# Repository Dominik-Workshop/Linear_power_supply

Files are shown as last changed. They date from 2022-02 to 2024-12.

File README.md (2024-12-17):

# Linear power supply

> [!CAUTION]
> This project was initiated in 2021 when my skills were more limited. As a result, there might be areas for improvement. I occasionally enhance both the performance and readability of project files for better understanding.

### More info about this project can be found on my channel: 
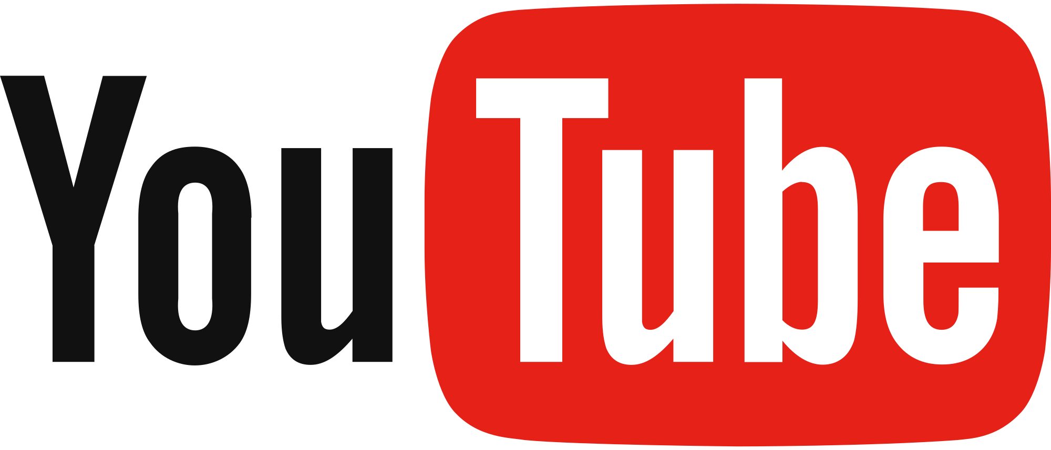
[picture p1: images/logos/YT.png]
 https://youtu.be/JCxF-o6tLgA

## Used tools:
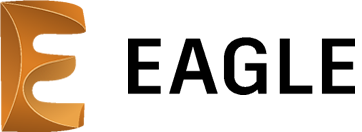
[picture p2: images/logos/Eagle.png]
 &nbsp;&nbsp;&nbsp;&nbsp; &nbsp;&nbsp;&nbsp;&nbsp; 
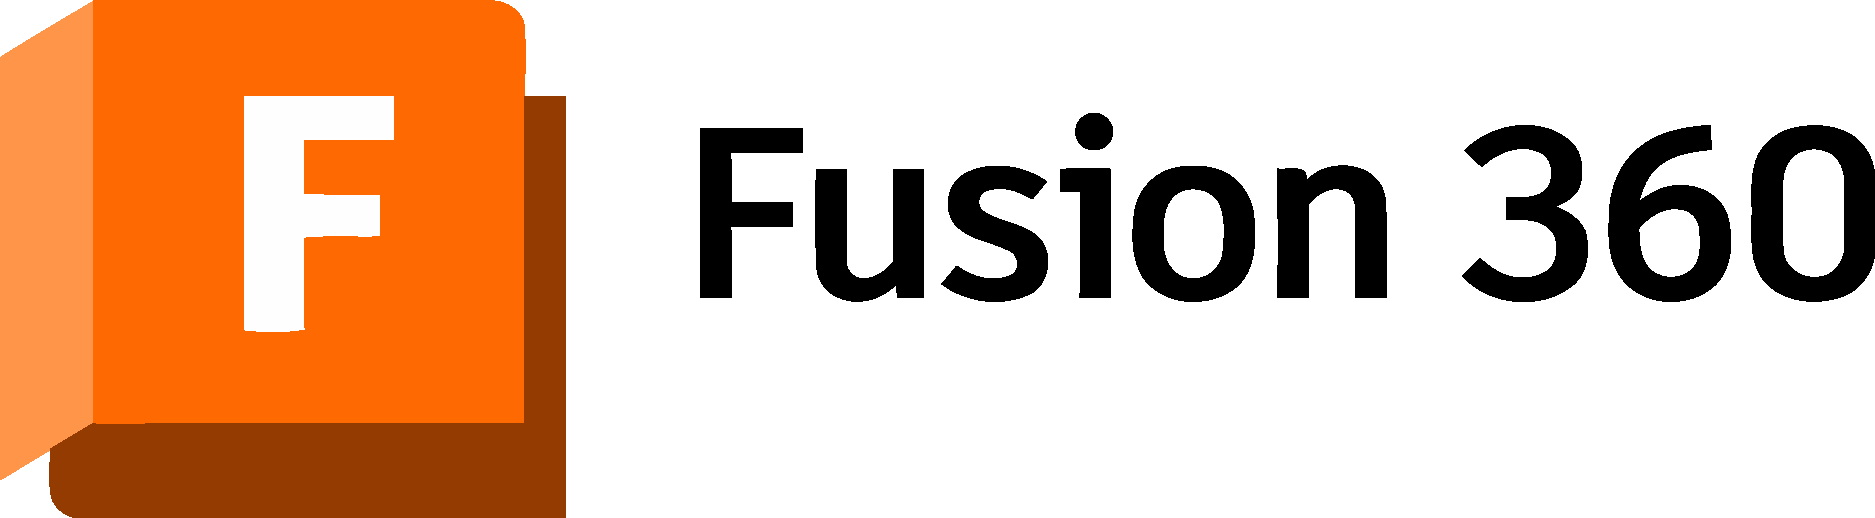
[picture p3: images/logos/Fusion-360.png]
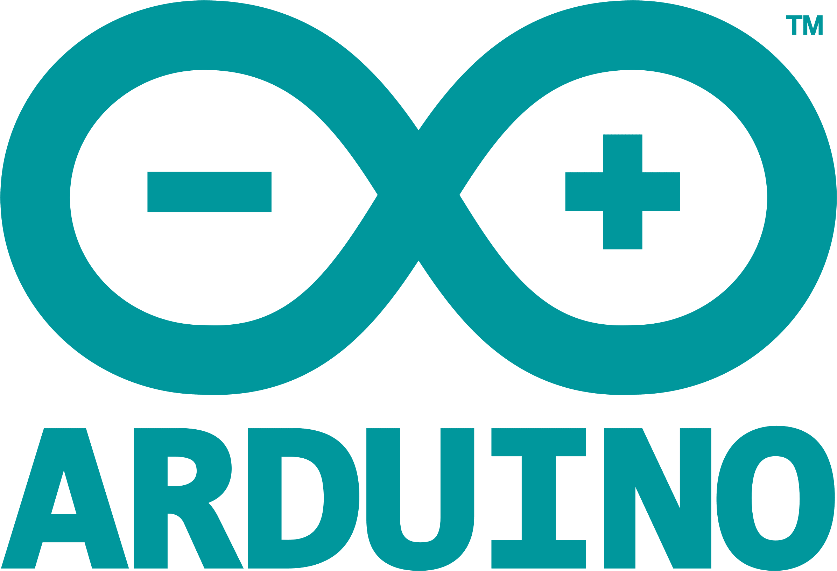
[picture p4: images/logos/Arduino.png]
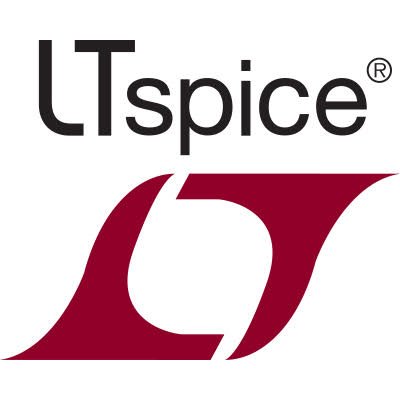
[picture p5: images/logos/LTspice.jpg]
&nbsp;&nbsp;&nbsp;&nbsp; &nbsp;&nbsp;&nbsp;&nbsp; &nbsp;&nbsp;&nbsp;&nbsp; &nbsp;&nbsp;&nbsp;&nbsp; 
#

## Project Overview
- Homemade linear power supply capable of delivering up to 250W (0-28V, 0.01-10A)
- Features adjustable voltage and current limit, controlled by 10-turn potentiometers.
- Incorporates an on/off switch for convenient power control.
- Utilizes a relay transformer-tab switching circuit to minimize power losses by reducing the voltage differential across the linear regulator.
- Enhanced heat dissipation through a temperature-controlled fan cooling the heatsink.

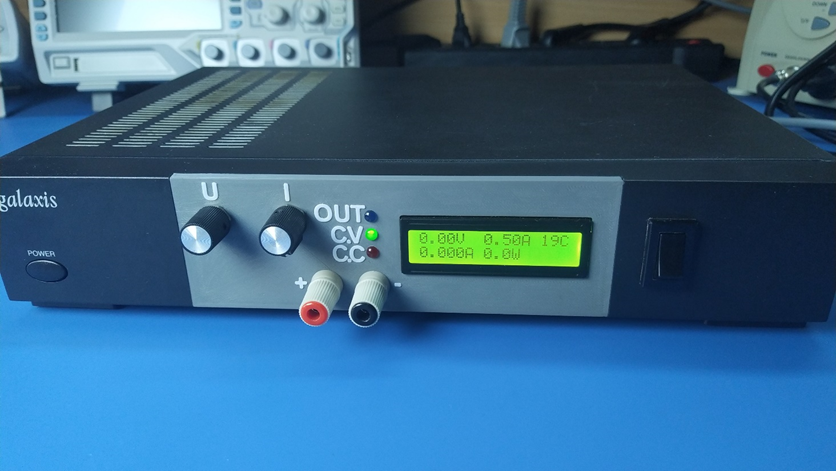
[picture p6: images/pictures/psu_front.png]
 

> [!IMPORTANT]
> I changed the Q1 transistor from IRF9530 (P-MOSFET) to BD912 (PNP-BJT) to greatly improve the stability of this power supply and completely eliminate oscillations in the constant current mode. (Their pinouts match, so it is a drop-in replacement)
> <details>
> <summary>Click to learn more</summary>
> After performing some simulations in LTspice, I figured out that simply changing the Q1 MOSFET to a BJT greatly improved the output response to input step:
>
> Before (with MOSFET):
> <image src="images/screenshots/old_step.png">
> After (with BJT):
> <image src="images/screenshots/new_step.png">
> (The bode plot also looks better)
> </details>

## Output Measurements
Output voltage waveforms before changing Q1 to a BJT can be found in measurements.pdf

## Project details
I used this 12 300VA transformer, which I slightly modified. The secondary winding consisted of 4 wires connected in parallel. I split them in 2 and connected in series, getting 24V with a center tap). Last but not least, I added another winding of around 8V.


I used an old graphics card's heatsink for cooling.


It was based on SN1534 power supply, its schematics can be found there as well.

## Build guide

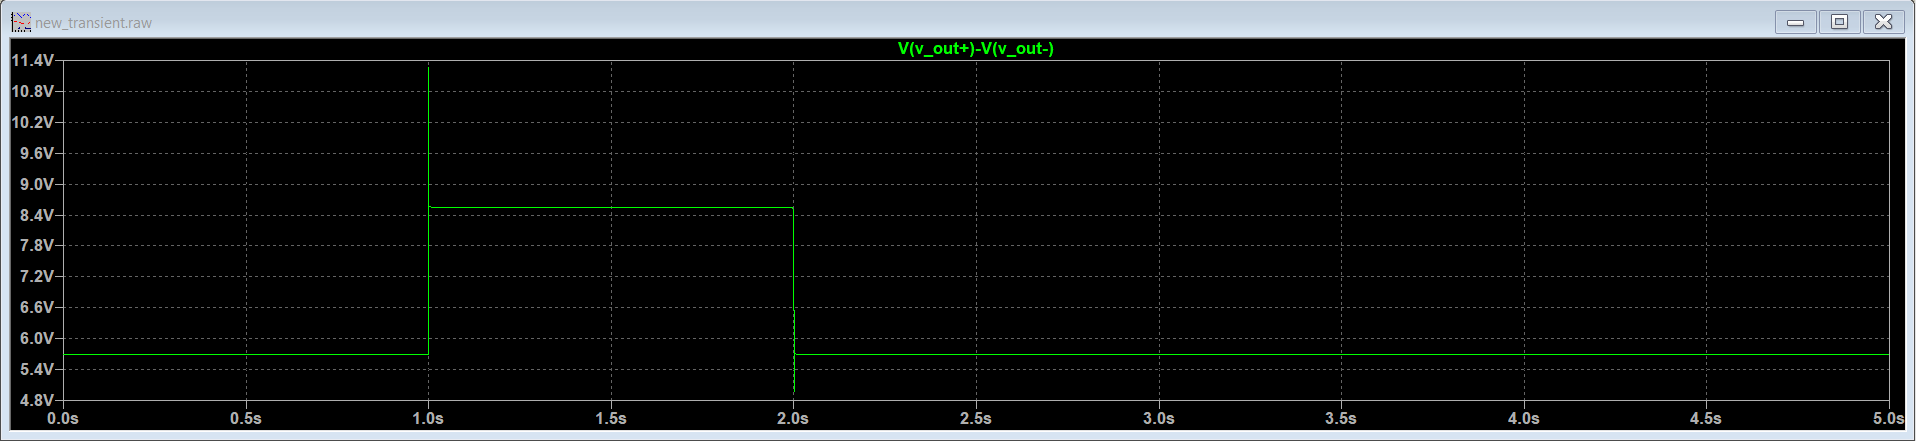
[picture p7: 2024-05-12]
images/screenshots/new_step.png

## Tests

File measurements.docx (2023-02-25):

1. Measurements results

Output voltage noise and ripple in CV mode: 35 mVpp (20MHz bandwidth)

9 mVRMS (20MHz bandwidth)

Output voltage noise and ripple in CC mode: 113 mVpp (20MHz bandwidth)

28 mVRMS (20MHz bandwidth)

These are the worst values rounded up, taken from the measurements shown bellow

(ignoring values from images 26 and 30, because there the power supply stops working correctly).

I also did measurements of the output voltage at switch-on/off.

Last but not least I performed transient response measurement.

The measurements were done using Rigol DS1054 with PVP2150 probe. The power supply was being loaded with my DIY electronic load using its constant current mode (https://github.com/Dominik-Workshop/Electronic_load).

Measurements shown in images 9, 27-29 were done with 4 ohm resistor acting as a load.

(comparing the image 9 and image 6 we can see that the power supply acts different when loaded with a resistor or a CC load).

The image 30 shows that the oscillations in CC mode occur with higher loads, so it looks like the old problem came back (last time I checked, over a year ago, these oscillations were absent).

It can also be observed that using the switching converter to power the fan and relay coil was a bad idea, because it introduces a lot of noise on the output of the power supply

(images 18 and 19). Most of the noise on the output noise comes from this switching converter.

2. Output voltage at switch-on
a) Vout = 5 [V]

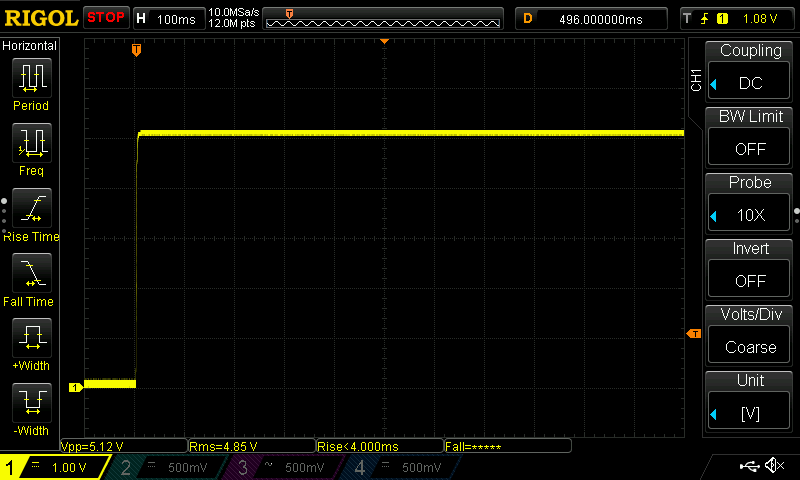
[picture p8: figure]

Image 1. Iout = 0 [A] Image 2. Iout = 8 [A]

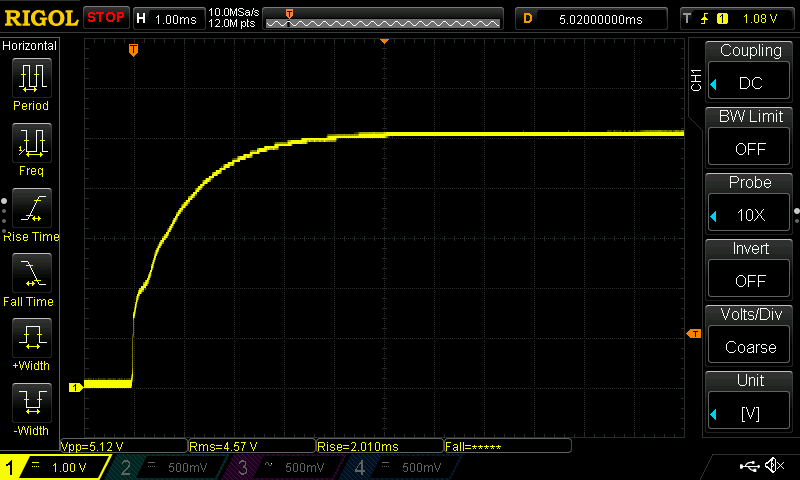
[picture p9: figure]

Image 3. Iout = 0 [A] zoomed in Image 4. Iout = 8 [A] zoomed in

b) Vout = 24 [V]

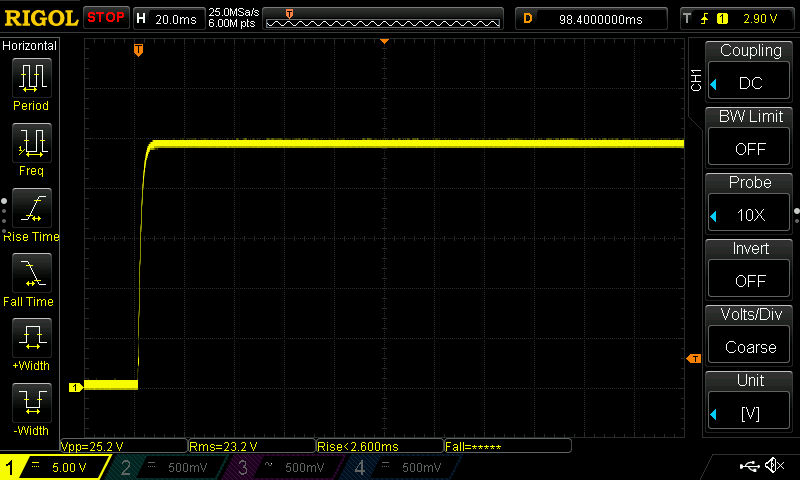
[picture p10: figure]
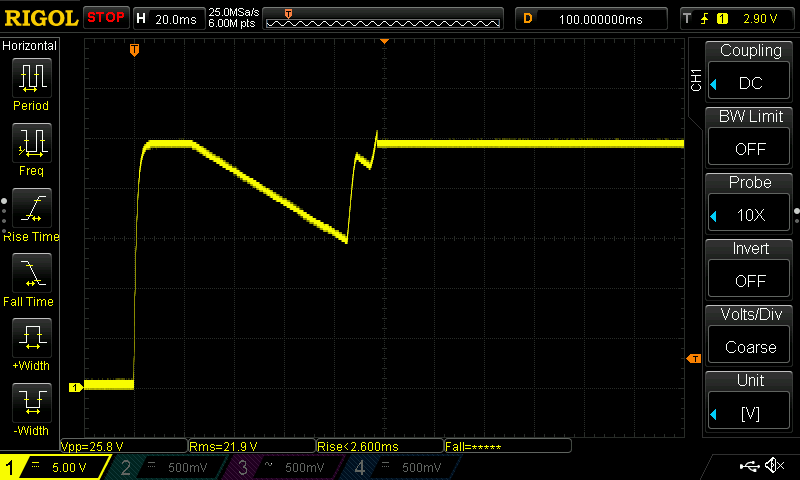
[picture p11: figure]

Image 5. Iout = 0 [A] Image 6. Iout = 5 [A]

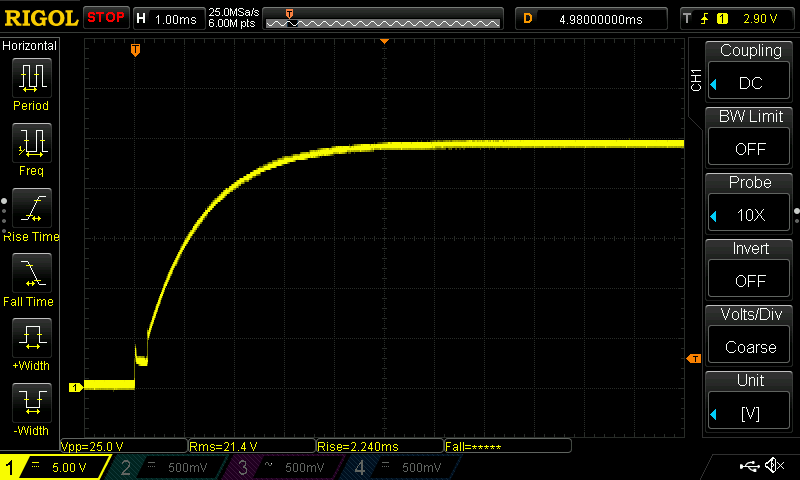
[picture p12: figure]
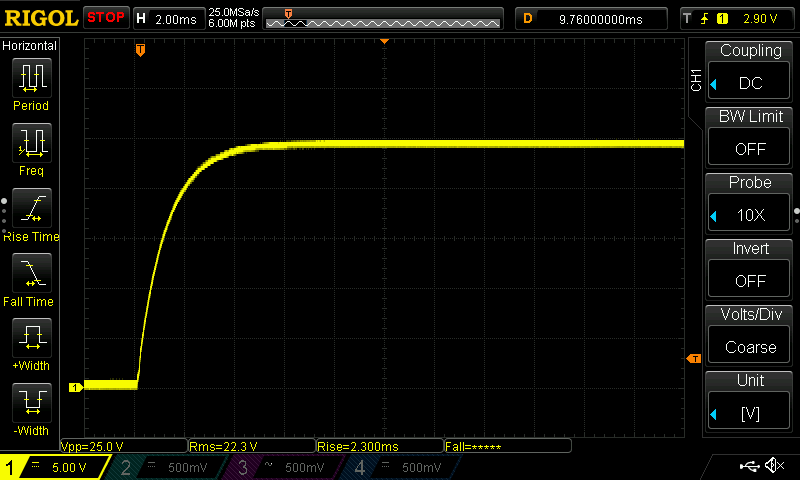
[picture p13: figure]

Image 7. Iout = 0 [A] zoomed in Image 8. Iout = 5 [A] zoomed in

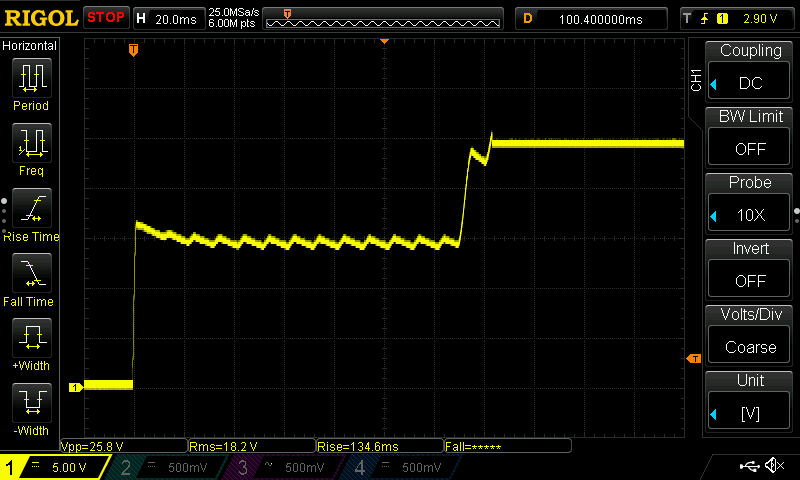
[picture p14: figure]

Image 9. Loaded with 4 ohm resistor

3. Output voltage at turn off
a) Vout = 5 [V]

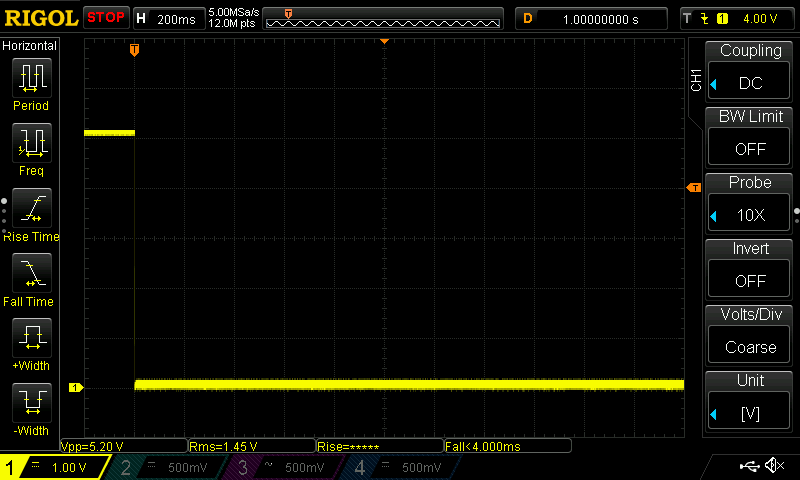
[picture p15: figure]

Image 10. Iout = 0 [A] Image 11. Iout = 8 [A]

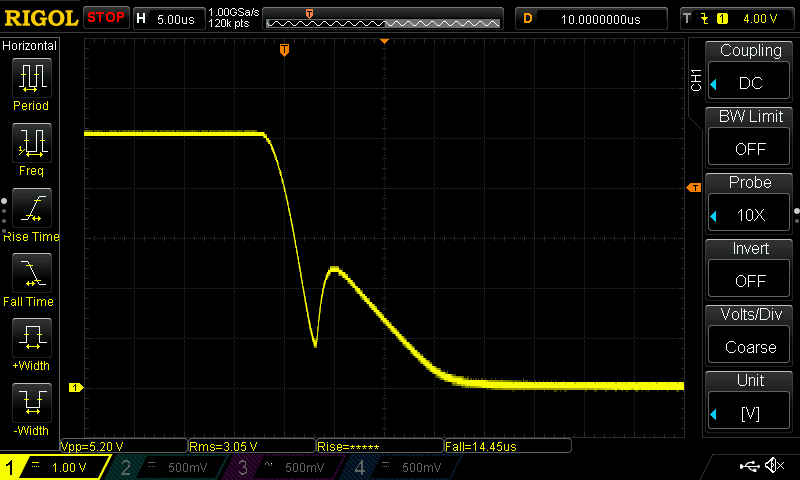
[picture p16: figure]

Image 12. Iout = 8 [A] zoomed in

b) Vout = 24 [V]

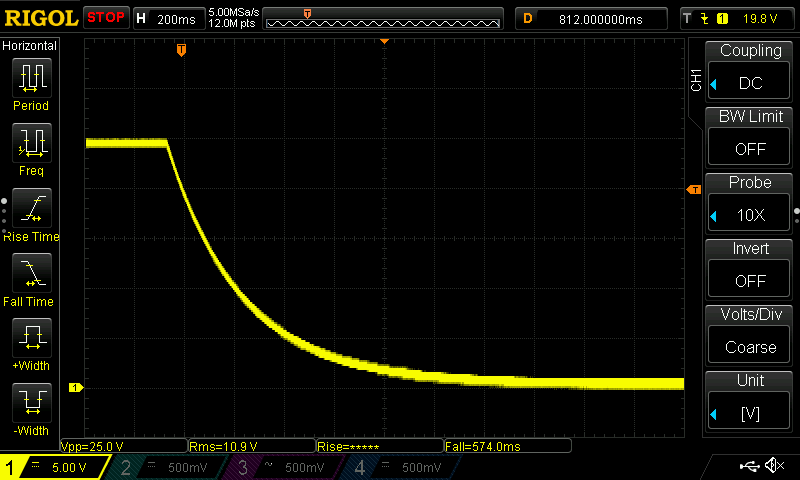
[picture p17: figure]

Image 13. Iout = 0 [A] Image 14. Iout = 8 [A]


Image 15. Iout = 8 [A] zoomed in

4. Output voltage noise and ripple in CV mode
a) Vout = 5 [V]


Image 16. Iout = 0 [A] Image 17. Iout = 2 [A]


Image 18. Iout = 8 [A] Image 19. Iout = 8 [A] when cooling fans are off

b) Vout = 12 [V]


Image 20. Iout = 0 [A] Image 21. Iout = 2 [A]


Image 22. Iout = 8 [A]

c) Vout = 24 [V]


Image 23. Iout = 0 [A] Image 24. Iout = 2 [A]


Image 25. Iout = 8 [A]

d) Vout = 25 [V]


Image 26. Iout = 10 [A]

(the voltage drop on the regulator is too small

and the ripple from bridge rectifier starts showing up on the output)

5. Output voltage noise and ripple in CC mode


Image 27. Iout = 1 [A] (4 ohms load) Image 28. Iout = 3 [A] (4 ohms load)


Image 29. Iout = 6 [A] (4 ohms load) Image 30. Iout = 6 [A] (shorted)

6. Transient response


Image 31. Vout = 24 [V], Iout switching between 1 [A] and 8 [A]

with period of 70 [ms]

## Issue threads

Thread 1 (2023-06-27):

LCD Library not declared in this scope

M0rxira1, 2023-06-27:
Can u provide the link to the especific library you used in the project
thank you

off topic question
   How is this voltage reaple of the supply in varius loads 0, 1 and all the way to 10A and across its voltage range ???

Dominik-Workshop, 2023-06-27:
As far as I remember I just used the library installed directly in the library manager in Arduino IDE.

The voltage ripple and noise measurements, along with transient response measurements are included in the file: measurements.pdf (in this repository).

Closed 2024-10-26.

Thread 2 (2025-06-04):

Compilation error

adil9279, 2025-06-04:
Compilation error: no matching function for call to 'Liquidcrystal_I2C;;begin()

Dominik-Workshop, 2025-06-04:
I'm assuming you are using the **Arduino IDE**.

I managed to reproduce your error using the library shown bellow:
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
To resolve the compilation error, please try changing line `58` from:
`lcd.begin();`
to
`lcd.init();`

This should fix the compilation. However, I currently don't have the hardware to test if this resolves all runtime issues on the PSU itself.

This is an older project, and I'm unfortunately unsure which specific library version was initially used.

Dominik-Workshop, 2025-06-10:
Just to be sure, it only prints:
```
Dominik Workshop
```
not
```
Dominik Workshop
      2021
```
right?

---
If so, you may try changing the `x` and `y` coordinates in the `setCursor()` method, mayby your library works different in that regards:

```
  lcd.setCursor(0, 0);
  lcd.print("Dominik Workshop");
  lcd.setCursor(6, 1);
  lcd.print(2021);
  delay(1500);
  lcd.clear();
```
Change to:

```
  lcd.setCursor(0, 0);
  lcd.print("Dominik Workshop");
  lcd.setCursor(1, 6);
  lcd.print(2021);
  delay(1500);
  lcd.clear();
```
---
If it doesn't help, you can check what happens, when you remove the greeting screen code section.

adil9279, 2025-06-10:
thanks for quick response :)

after changes in code

my 16*2 display does not showing anything only backlight is ON.

iam not using ADC right now only arduino and lcd for testing purpose.

Dominik-Workshop, 2025-06-10:
Since you're not using the `ADS1115` ADC right now, and the Arduino is expecting it, there's a good chance it's getting stuck trying to communicate with a device that isn't there.

Please comment out all `ads.begin()`, `ads.readADC...()`, or other ADC-related calls in your code and test again.

This might let the LCD code run normally.

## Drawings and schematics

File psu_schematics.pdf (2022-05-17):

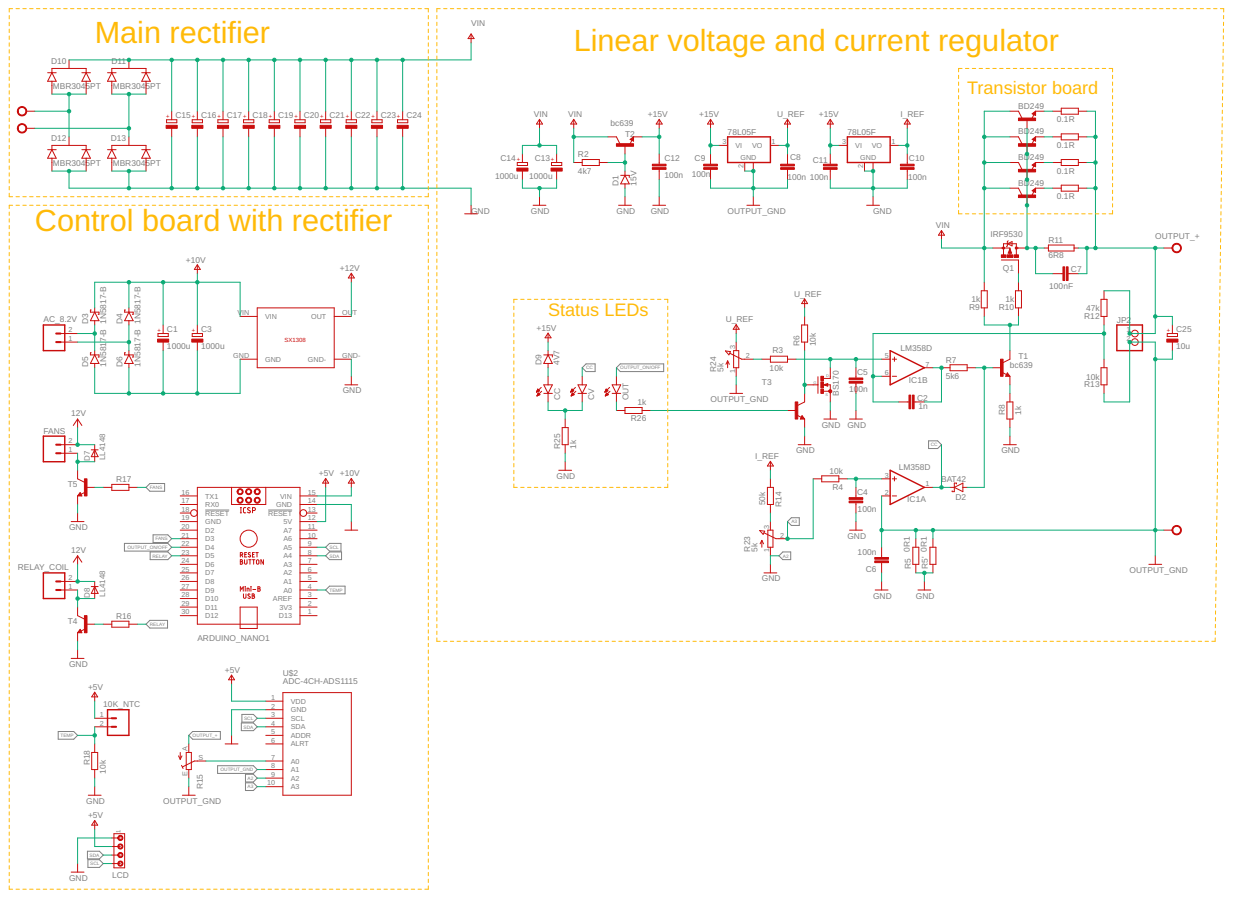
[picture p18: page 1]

Linear voltage and current regulator

Control board with rectifier

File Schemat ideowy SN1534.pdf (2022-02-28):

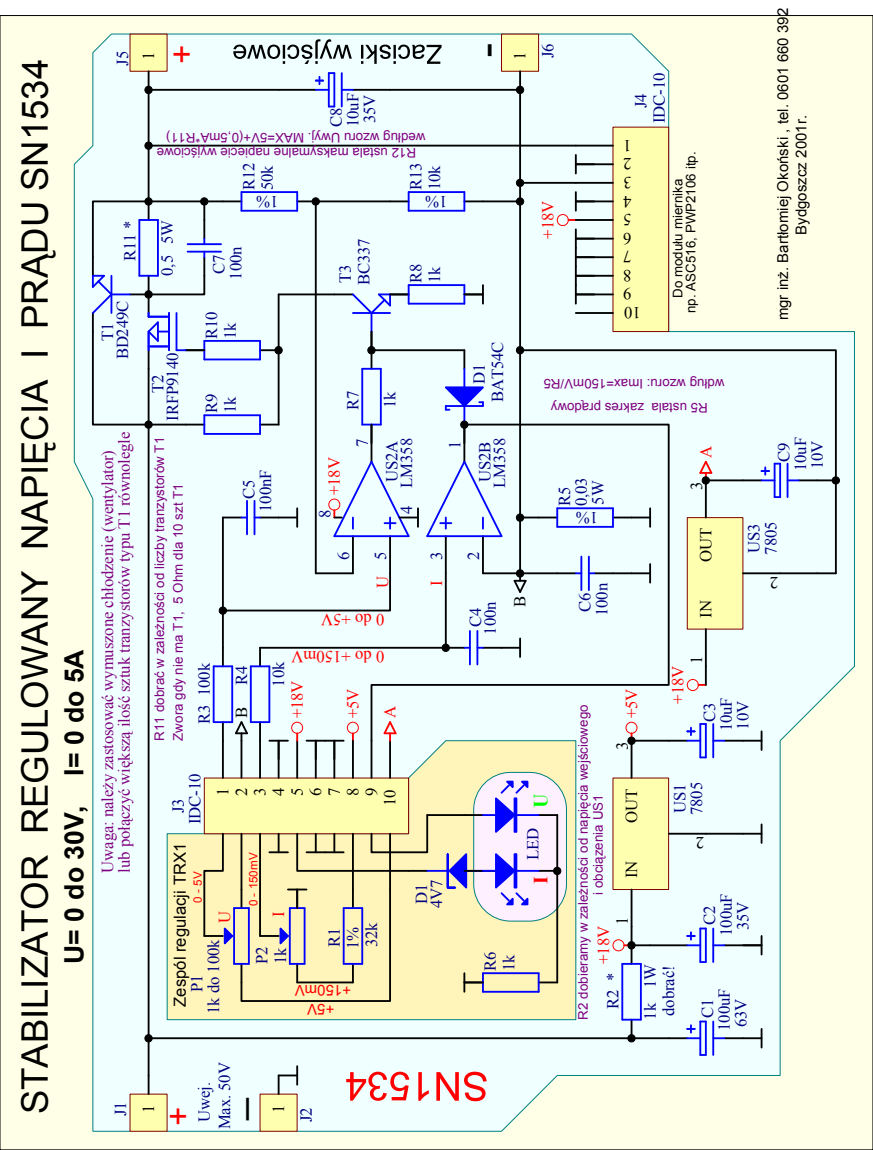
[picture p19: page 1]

mgr inż. Bartłomiej Okoński , tel. 0601 660 392

STABILIZATOR REGULOWANY NAPIĘCIA I PRĄDU SN1534

lub połączyć większą ilość sztuk tranzystorów typu T1 równolegle

R11 dobrać w zależności od liczby tranzystorów T1

Uwaga: należy zastosować wymuszone chłodzenie (wentylator)

Zwora gdy nie ma T1, 5 Ohm dla 10 szt T1

R2 dobieramy w zależności od napięcia wejściowego

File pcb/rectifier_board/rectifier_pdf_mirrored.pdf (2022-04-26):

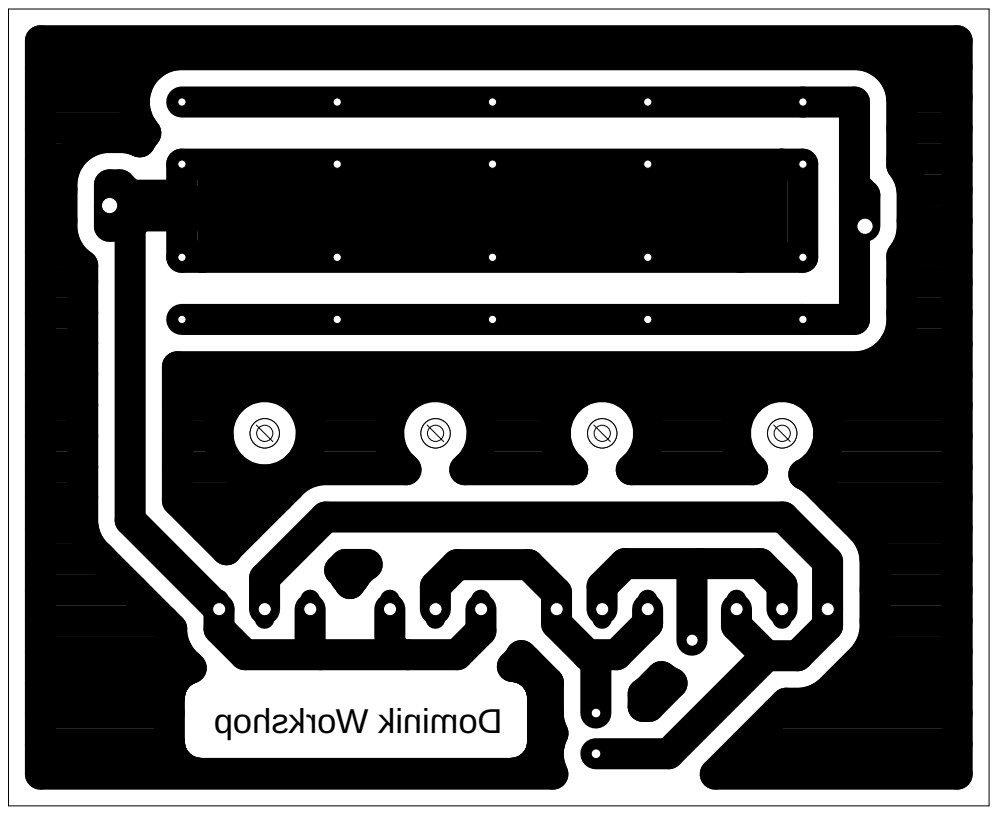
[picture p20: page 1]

pohskr o Wki ni mo D

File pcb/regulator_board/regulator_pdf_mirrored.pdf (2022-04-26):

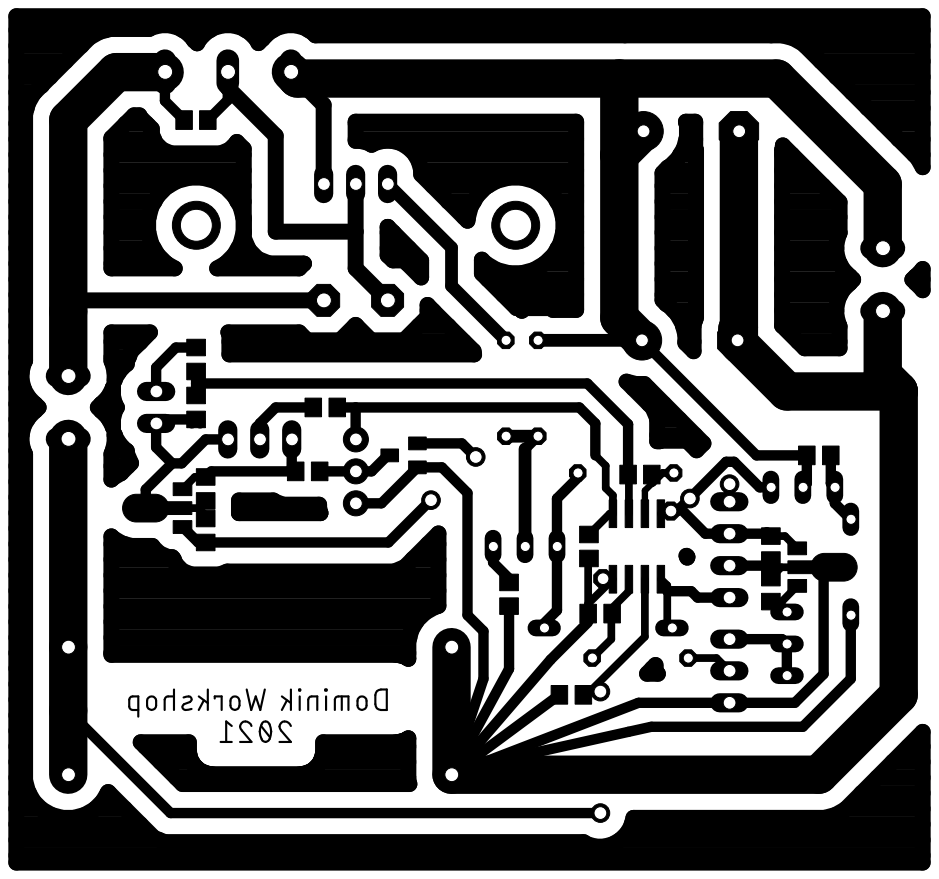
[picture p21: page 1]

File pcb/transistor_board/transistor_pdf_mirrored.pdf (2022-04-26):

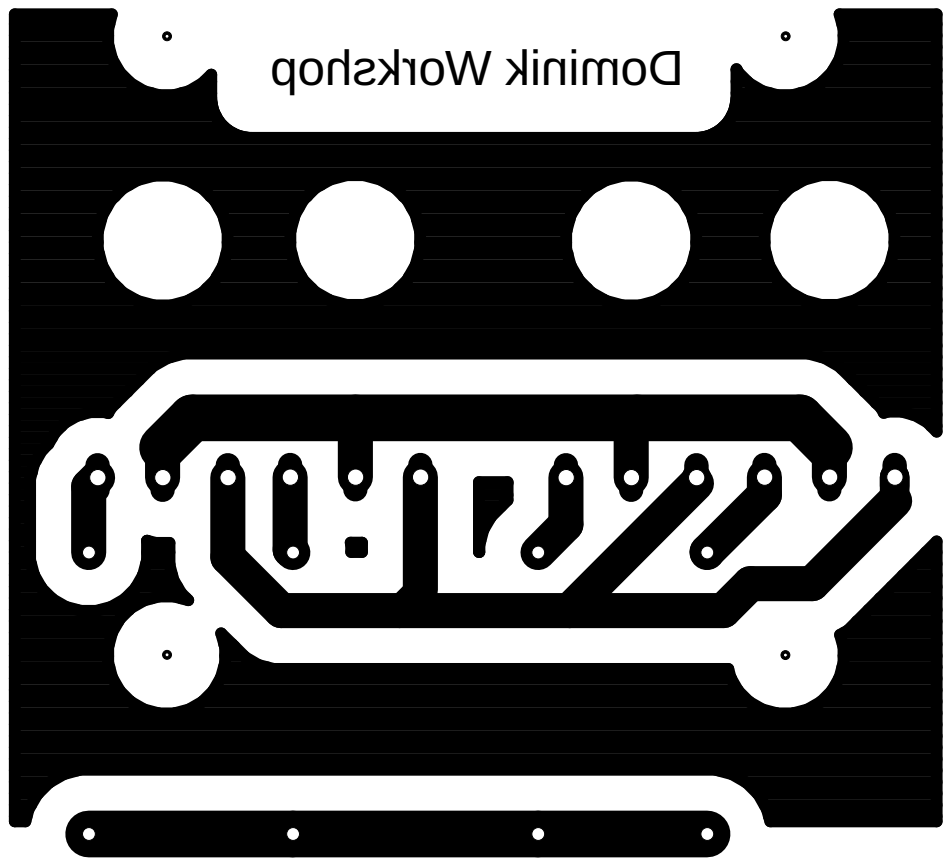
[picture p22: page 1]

pohskr o Wki ni mo D

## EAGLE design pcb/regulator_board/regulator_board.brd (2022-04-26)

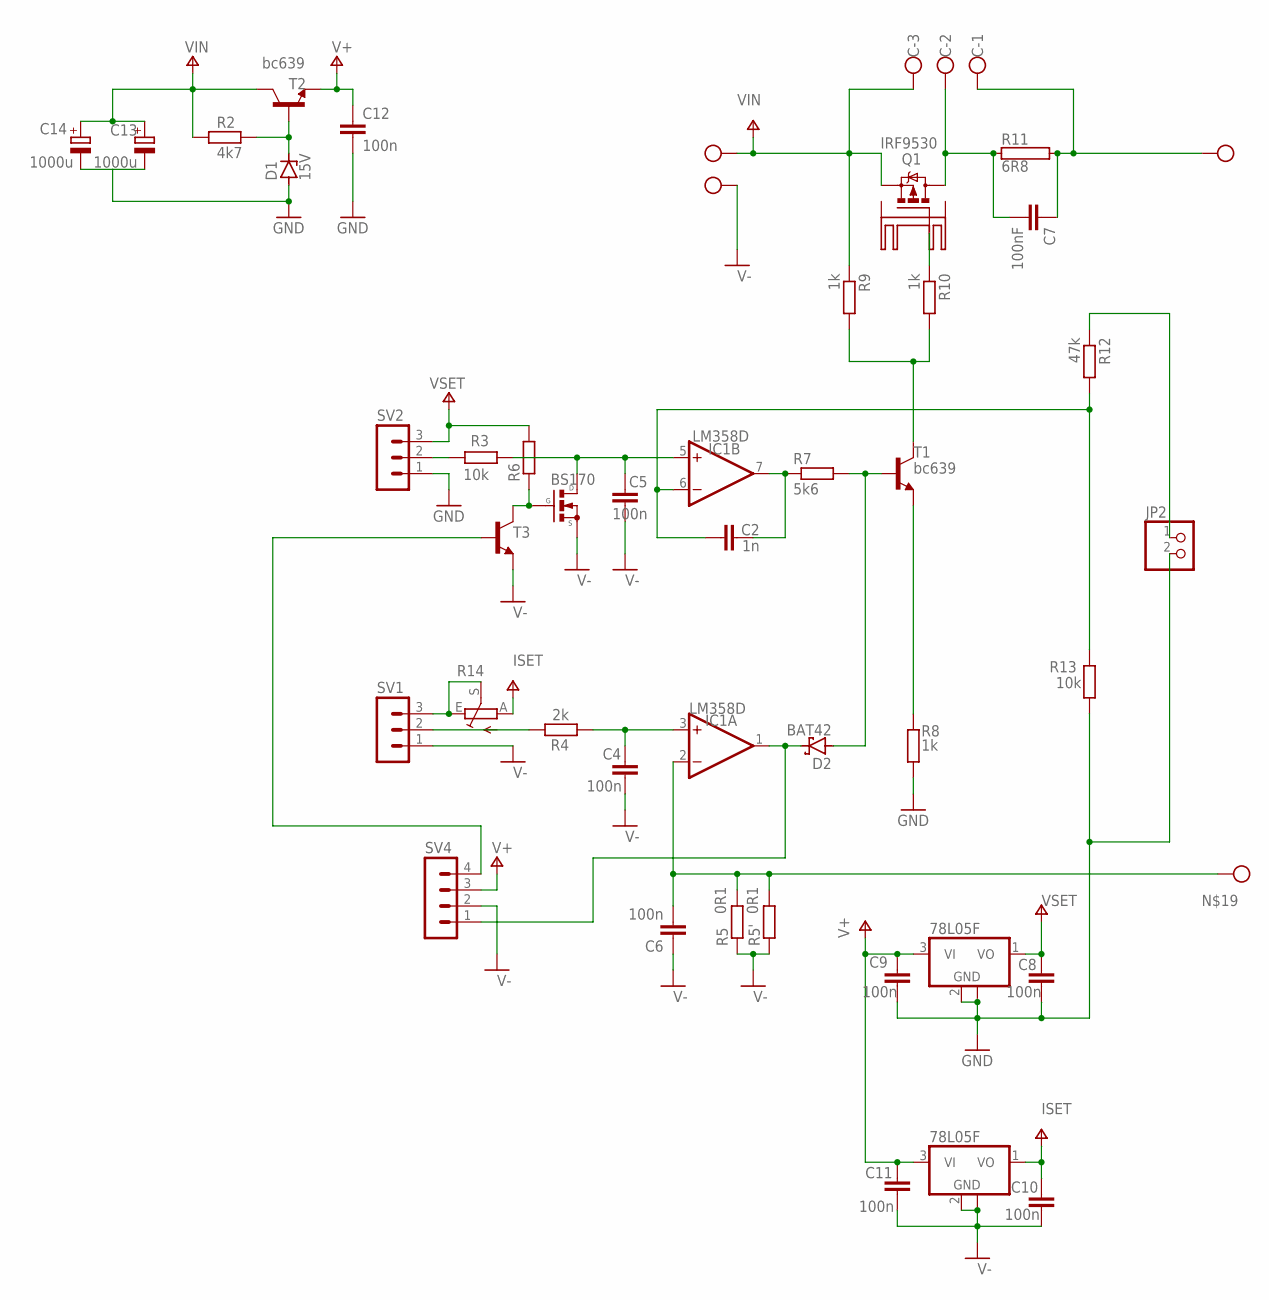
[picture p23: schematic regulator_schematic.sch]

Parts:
C: W237-103
C2: 1n; C0805
C4, C5, C6, C8, C9, C10, C11: 100n; C0805
C7: 100nF; C0805
C12: 100n; C075-032X103
C13, C14: 1000u; E7,5-16
D1: 15V; DO34Z7
D2: BAT42; DO35-10
IC1: LM358D; SO08
IC2, IC3: 78L05F; SOT89
JP2: PINHD-1X2; 1X02
KK1: SK104-PAD
Q1: IRF9530; TO220BV
Q3: BS170; SOT54ES
R2: 4k7; R0805
R3, R13: 10k; R0805
R4: 2k; 0204/7
R5, R5': 0R1; VTA52
R6: R-EU_R0805; R0805
R7: 5k6; 0204/7
R8: 1k; R0805
R9, R10: 1k; 0204/7
R11: 6R8; MNS-5
R12: 47k; R0805
R14: TRIM_EU-B64Y; B64Y
SV1, SV2: MA03-1
SV4: MA04-1
T1, T2: bc639; TO92-ECB
T3: BC817-16-NPN-SOT23-BEC; SOT23-BEC
X1, X2: W237-102

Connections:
GND: C8.1, C9.1, IC2.2 (GND), IC2.2@1 (GND), JP2.2, R13.2, SV2.1
ISET: C10.2, IC3.1 (VO), R14.A
unnamed: D2.C, IC1.1 (OUT), SV4.1
unnamed: C5.2, IC1.5 (+IN), Q3.D, R3.1
unnamed: C4.2, IC1.3 (+IN), R4.1
unnamed: C2.2, IC1.7 (OUT), R7.1
unnamed: D2.A, R7.2, T1.B
unnamed: R8.2, T1.E
unnamed: C2.1, IC1.6 (-IN), R12.2, R13.1
unnamed: R3.2, SV2.2
unnamed: C.2, C7.2, Q1.D, R11.1
unnamed: C.1, C7.1, R11.2, X1.2
unnamed: R14.E, R14.S, SV1.3
unnamed: R4.2, SV1.2
unnamed: D1.C, R2.2, T2.B
unnamed: Q3.G, R6.1, T3.C
unnamed: Q1.G, R10.1
unnamed: SV4.4, T3.B
unnamed: R9.2, R10.2, T1.C
unnamed: JP2.1, R12.1
unnamed: C6.2, IC1.2 (-IN), R5.2, R5'.2, X1.1
V+: C9.2, C11.2, C12.1, IC1.8 (V+), IC2.3 (VI), IC3.3 (VI), SV4.3, T2.E
V-: C4.1, C5.1, C6.1, C10.1, C11.1, C12.2, C13.-, C14.-, D1.A, IC1.4 (V-), IC3.2 (GND), IC3.2@1 (GND), Q3.S, R5.1, R5'.1, R8.1, SV1.1, SV4.2, T3.E, X2.2
VIN: C.3, C13.+, C14.+, Q1.S, R2.1, R9.1, T2.C, X2.1
VSET: C8.2, IC2.1 (VO), R6.2, SV2.3

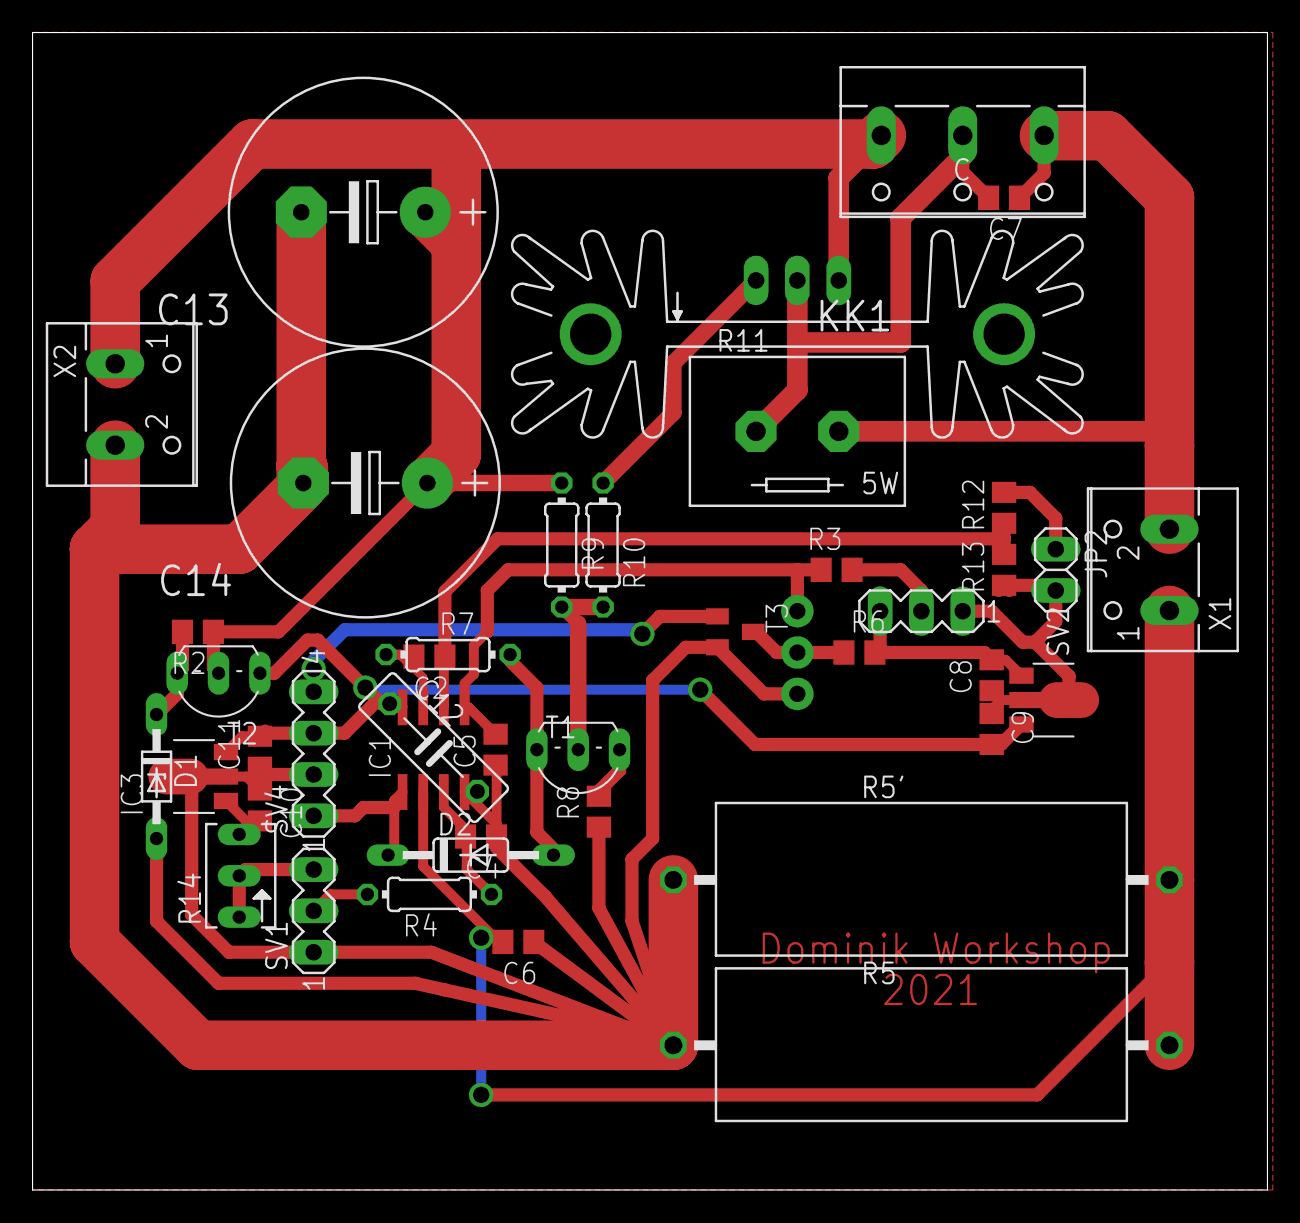
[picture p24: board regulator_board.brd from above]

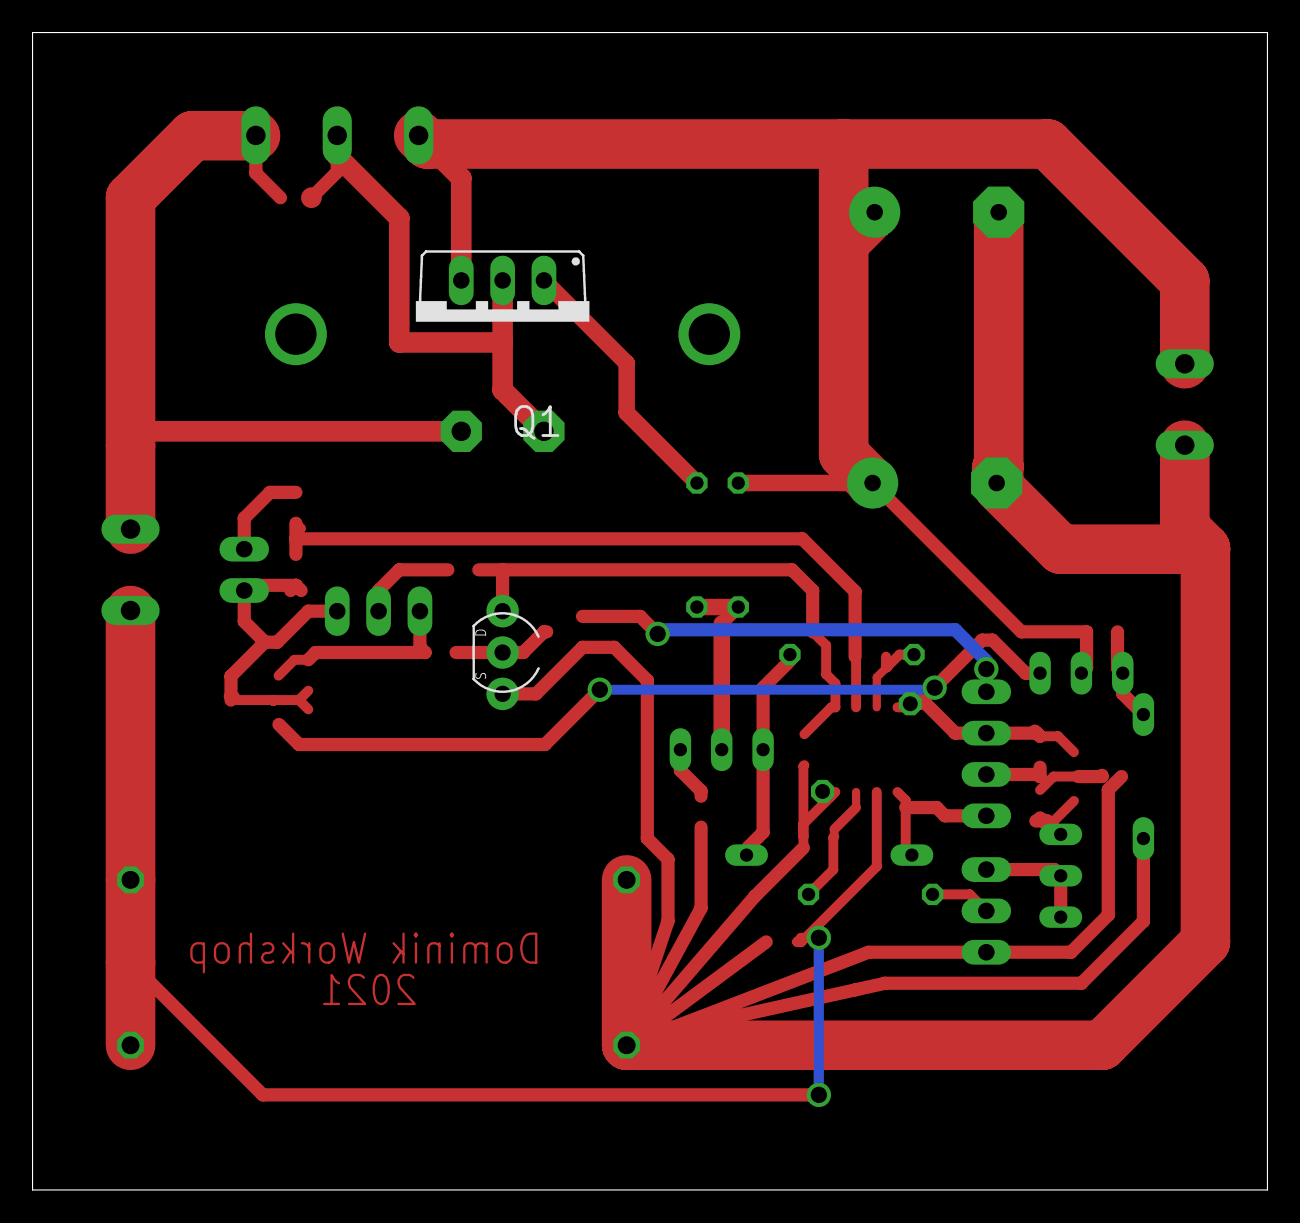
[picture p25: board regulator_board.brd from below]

Board: 2 copper layers, 75.9 x 71.1 mm, 44 parts (2 on the bottom side), 25 nets.

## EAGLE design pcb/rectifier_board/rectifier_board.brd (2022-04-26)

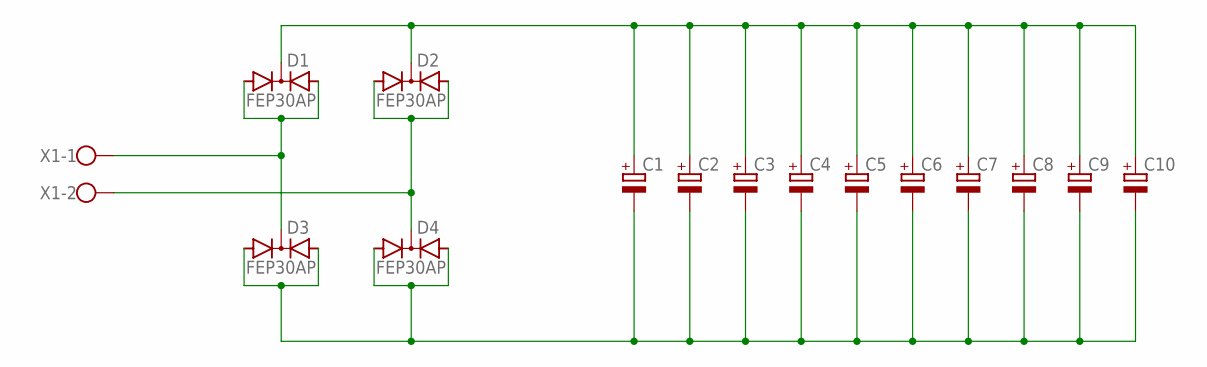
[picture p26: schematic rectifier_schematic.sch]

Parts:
C1, C2, C3, C4, C5, C6, C7, C8, C9, C10: CPOL-EUE7.5-18; E7,5-18
D1, D2, D3, D4: FEP30AP; TO3P
X1: W237-102

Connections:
unnamed: D1.1 (A1), D1.3 (A2), D3.2 (C), X1.1
unnamed: D2.1 (A1), D2.3 (A2), D4.2 (C), X1.2
unnamed: C1.-, C2.-, C3.-, C4.-, C5.-, C6.-, C7.-, C8.-, C9.-, C10.-, D3.1 (A1), D3.3 (A2), D4.1 (A1), D4.3 (A2)
unnamed: C1.+, C2.+, C3.+, C4.+, C5.+, C6.+, C7.+, C8.+, C9.+, C10.+, D1.2 (C), D2.2 (C)

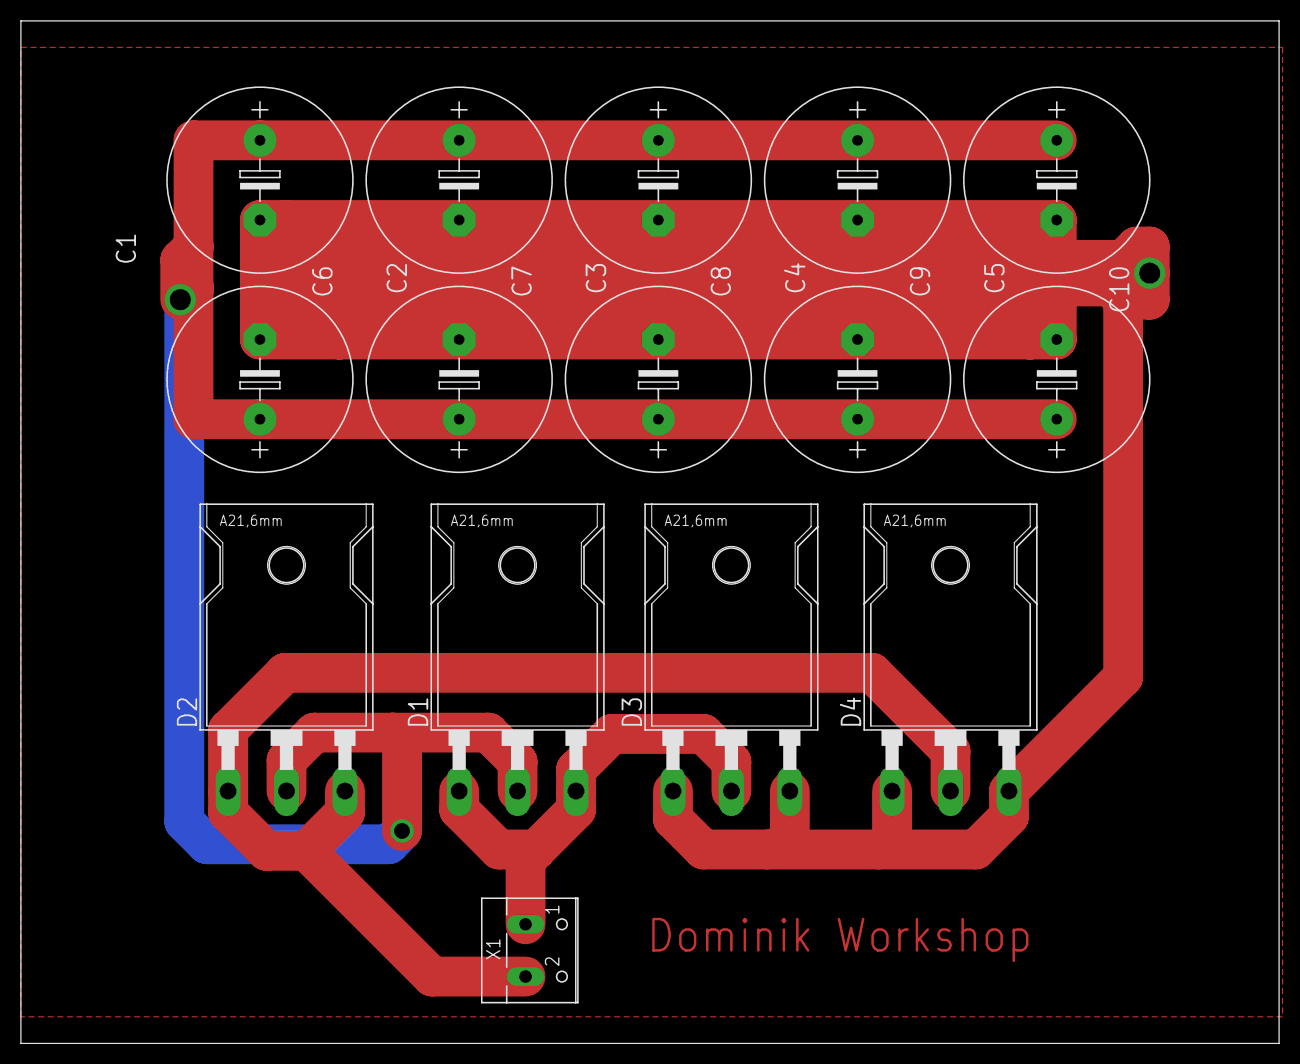
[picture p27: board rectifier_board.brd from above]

Board: 2 copper layers, 120.3 x 97.8 mm, 15 parts (0 on the bottom side), 4 nets.

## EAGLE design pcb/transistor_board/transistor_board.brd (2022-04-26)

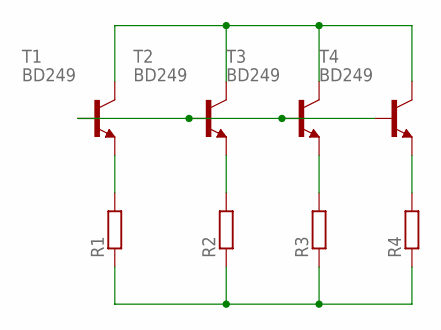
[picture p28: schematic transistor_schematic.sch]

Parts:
R1, R2, R3, R4: R-EU_VTA53; VTA53
T1, T2, T3, T4: BD249; TOP3

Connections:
unnamed: R1.2, T1.3 (E)
unnamed: R2.2, T2.3 (E)
unnamed: R3.2, T3.3 (E)
unnamed: R1.1, R2.1, R3.1, R4.1
unnamed: T1.2 (C), T2.2 (C), T3.2 (C), T4.2 (C)
unnamed: T1.1 (B), T2.1 (B), T3.1 (B), T4.1 (B)
unnamed: R4.2, T4.3 (E)

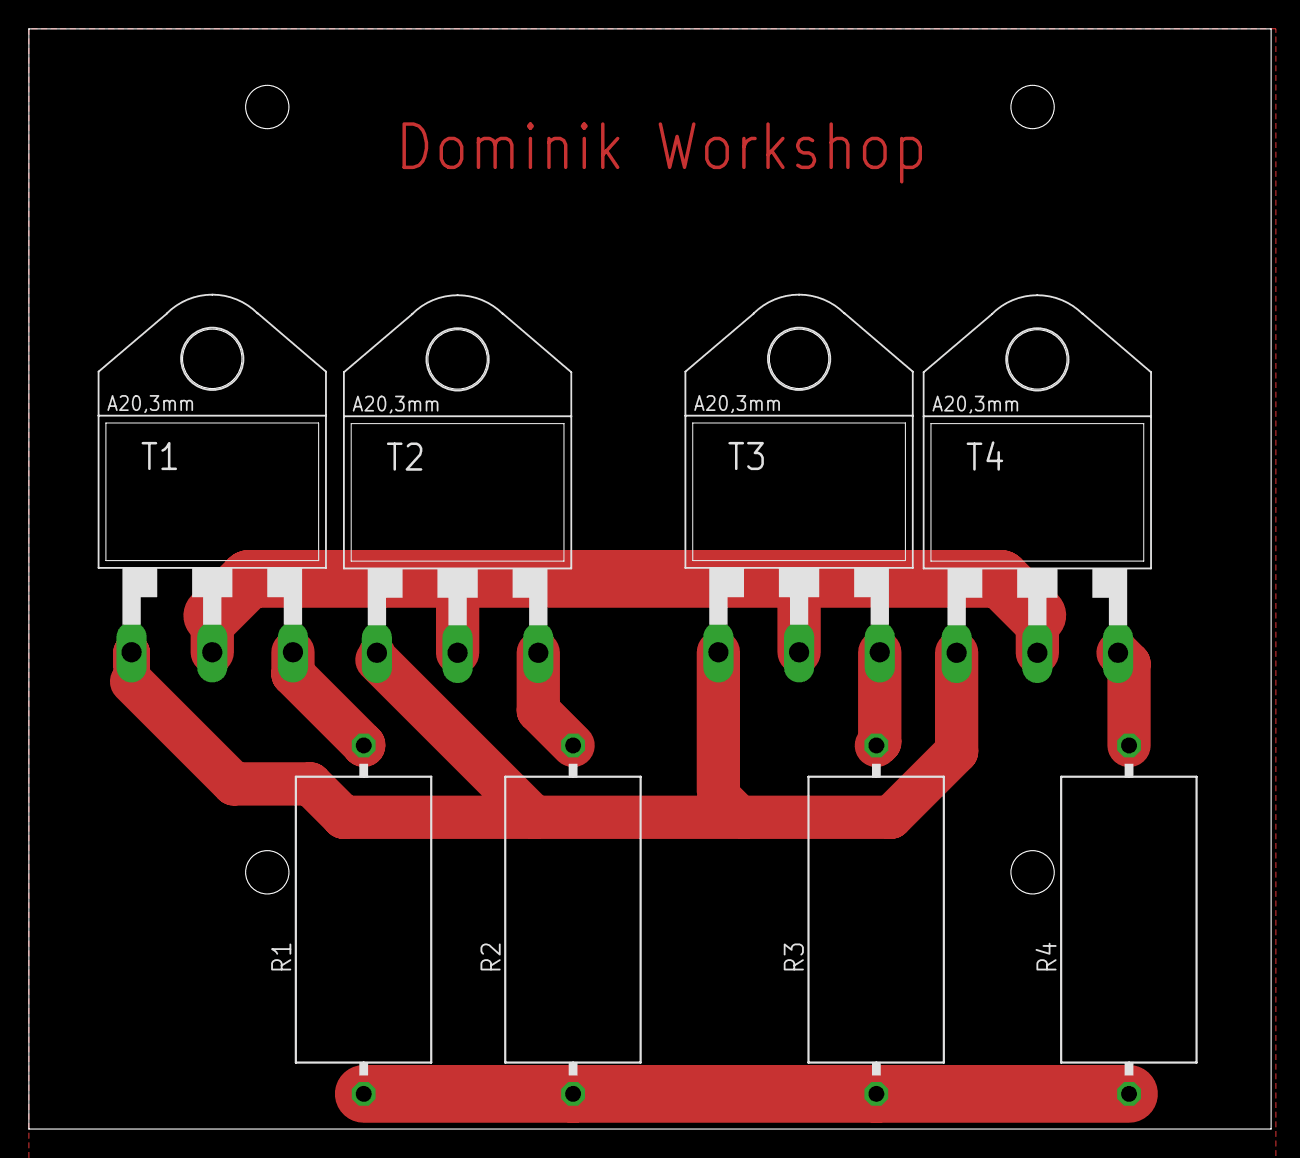
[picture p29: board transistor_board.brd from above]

Board: 2 copper layers, 86.0 x 76.2 mm, 8 parts (0 on the bottom side), 7 nets.

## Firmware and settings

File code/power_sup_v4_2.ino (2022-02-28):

/**
 * @author Dominik Workshop
 * @date 15.02.2022
 * @version 4.2 (minor changes, seperate function for moving average)
 */
  
  #define FAN 3                           //pin 3 controlls the fans
  #define OUTPUT_PS 4                     //pin 4 can switch off the output of the power supply
  #define RELAY 5                         //pin 5 controlls the relay that switches the transformer tap
  #define THERMISTOR_PIN  A0              //voltage divider with a thermistor measuring the heatsink's temperature, connected to pin A0
  #define OVER_TEMPERATURE_PROTECTION 55  //power supply turns off the output above this temperature

  float VoltageThreshold = 13.5; //voltage threshold to switch the transformer tap
  int TempThreshold = 30;       //tempearature threshold to turn on the cooling fans 
  int Fanspeed;

  int Vo;
  float R1 = 10000;
  float logR2, R2;
  int T;                   // T = temperature
  float c1 = 1.009249522e-03, c2 = 2.378405444e-04, c3 = 2.019202697e-07;

  const int numReadings = 6; //number of readings for moving average filter

  float I_readings[numReadings];      // the readings from the analog input
  int I_readIndex = 0;              // the index of the current reading
  float I_total = 0;                  // the running total
  float I_average = 0;                // the average

  float U_readings[numReadings];      // the readings from the analog input
  int U_readIndex = 0;              // the index of the current reading
  float U_total = 0;                  // the running total
  float U_average = 0;                // the average

  float I_set_readings[numReadings];      // the readings from the analog input
  int I_set_readIndex = 0;              // the index of the current reading
  float I_set_total = 0;                  // the running total
  float I_set_average = 0;                // the average
  
  #include <Adafruit_ADS1X15.h>
  #include <Wire.h>
  #include <LiquidCrystal_I2C.h>
  #include <stdio.h>

  Adafruit_ADS1115 ads;   //Use this for the 16-bit version 
  //Adafruit_ADS1015 ads;   //Use this for the 12-bit version 

  LiquidCrystal_I2C lcd(0x27, 16, 2); // Set the LCD address to 0x27 for a 16 chars and 2 line display

void setup(void){

  pinMode(FAN, OUTPUT); 
  pinMode(OUTPUT_PS, OUTPUT); 
  pinMode(RELAY, OUTPUT); 
  
  TCCR2B = TCCR2B & B11111000 | B00000001; //increase the pwm speed
  
  lcd.begin();
  ads.begin();
   
  // The ADC input range (or gain) can be changed via the following
  // functions, but be careful never to exceed VDD +0.3V max, or to
  // exceed the upper and lower limits if you adjust the input range!
  // Setting these values incorrectly may destroy your ADC!
  //                                                                ADS1015  ADS1115
  //                                                                -------  -------
  // ads.setGain(GAIN_TWOTHIRDS);  // 2/3x gain +/- 6.144V  1 bit = 3mV      0.1875mV (default)
  // ads.setGain(GAIN_ONE);        // 1x gain   +/- 4.096V  1 bit = 2mV      0.125mV
  // ads.setGain(GAIN_TWO);        // 2x gain   +/- 2.048V  1 bit = 1mV      0.0625mV
  // ads.setGain(GAIN_FOUR);       // 4x gain   +/- 1.024V  1 bit = 0.5mV    0.03125mV
  ads.setGain(GAIN_EIGHT);      // 8x gain   +/- 0.512V  1 bit = 0.25mV   0.015625mV
  // ads.setGain(GAIN_SIXTEEN);    // 16x gain  +/- 0.256V  1 bit = 0.125mV  0.0078125mV

  //show a greeting screen
  lcd.setCursor(0, 0);         
  lcd.print("Dominik Workshop");
  lcd.setCursor(6, 1);  
  lcd.print(2021);
  delay(1500);
  lcd.clear();

  //set all elements of arrays for the moving average filter to zero
  for (int thisReading = 0; thisReading < numReadings; thisReading++) {
    I_readings[thisReading] = 0;
    U_readings[thisReading] = 0;
    I_set_readings[thisReading] = 0;
  }
  
}

void MovingAverageFilter(float amps, float volts, float setcurrent){
    // subtract the last reading:
  I_total = I_total - I_readings[I_readIndex];
  // read from the sensor:
  I_readings[I_readIndex] = amps;
  // add the reading to the total:
  I_total = I_total + I_readings[I_readIndex];
  // advance to the next position in the array:
  I_readIndex = I_readIndex + 1;
  // if we're at the end of the array...
  if (I_readIndex >= numReadings) {
    // ...wrap around to the beginning:
    I_readIndex = 0;
  }
  // calculate the average:
  I_average = I_total / numReadings;


    // subtract the last reading:
  U_total = U_total - U_readings[U_readIndex];
  // read from the sensor:
  U_readings[U_readIndex] = volts;
  // add the reading to the total:
  U_total = U_total + U_readings[U_readIndex];
  // advance to the next position in the array:
  U_readIndex = U_readIndex + 1;
  // if we're at the end of the array...
  if (U_readIndex >= numReadings) {
    // ...wrap around to the beginning:
    U_readIndex = 0;
  }
  // calculate the average:
  U_average = U_total / numReadings;


  // subtract the last reading:
  I_set_total = I_set_total - I_set_readings[I_set_readIndex];
  // read from the sensor:
  I_set_readings[I_set_readIndex] = setcurrent;
  // add the reading to the total:
  I_set_total = I_set_total + I_set_readings[I_set_readIndex];
  // advance to the next position in the array:
  I_set_readIndex = I_set_readIndex + 1;
  // if we're at the end of the array...
  if (I_set_readIndex >= numReadings) {
    // ...wrap around to the beginning:
    I_set_readIndex = 0;
  }
  // calculate the average:
  I_set_average = I_set_total / numReadings;
}

void loop(void){
  int16_t adc0, adc1, adc2;
  float amps, volts, setcurrent;
  
  adc0 = ads.readADC_SingleEnded(1);      //measure voltage drop on a shunt resistor referenced to ground
  adc1 = ads.readADC_Differential_0_1();  //measure voltage from a voltage divider from output of the power supply
  adc2 = ads.readADC_Differential_2_3();  //measure voltage on 'current set' poteniometer

  amps = ((adc0)/2876.0);         //you can calibrate measured current here
  volts = ((adc1)/1104.6);        //you can calibrate measured voltage here
  setcurrent = ((adc2)/2613.0);   //you can calibrate set current here

  MovingAverageFilter(amps, volts, setcurrent);          //apply a moving average filter to current, voltage and setcurrent

  //ignore negative values
  if(I_average<0){
  I_average = 0;    
  }
  if(U_average<0){
  U_average = 0;    
  }
  if(I_set_average<0){
  I_set_average = 0;    
  }
  if(volts<0){
  volts = 0;    
  }

  //calculate temperature
  Vo = analogRead(THERMISTOR_PIN);
  R2 = R1 * (1023.0 / (float)Vo - 1.0);
  logR2 = log(R2);
  T = (1.0 / (c1 + c2*logR2 + c3*logR2*logR2*logR2));
  T = T - 273.15;
  //T = (T * 9.0)/ 5.0 + 32.0; //converting the tempereture reading to Fahrenheit

  Fanspeed = map(T , TempThreshold, 50, 100, 255); //calculate current fan speed
  
  //hysteresis, so that fans don't turn on/off repeatedly when crossing the threshold
  if (T < TempThreshold){
    Fanspeed = 0;
    TempThreshold = 31;
  }
  if (T >= TempThreshold){
    TempThreshold=30;
  }
  //if it's hot drive fans at full speed
  if (T > 50){
    Fanspeed = 255;
  }
  //disable the output when it overheats
  if(T > OVER_TEMPERATURE_PROTECTION){
    digitalWrite(OUTPUT_PS, LOW);
  }
  else{
    digitalWrite(OUTPUT_PS, HIGH);
  }

  lcd.setCursor(0, 0);
  lcd.print(U_average);  //display measured output voltage
  lcd.print("V ");

  lcd.setCursor(7, 0);
  if (I_set_average >= 10){
    lcd.print(I_set_average, 1);    //display set output current with 1 decimal place
  } else lcd.print(I_set_average);  //display set output current with 2 decimal places
  lcd.print("A ");

  lcd.setCursor(13, 0);  
  lcd.print(T);  //display measured teperature
  //lcd.write(0);
  lcd.print("C");
  
  lcd.setCursor(0, 1); 
  if (I_average >= 10){
     lcd.print(I_average);        //display measured output current with 2 decimal places
  }else lcd.print(I_average,3);   //display measured output current with 3 decimal places
  lcd.print("A");
  
  lcd.setCursor(7, 1);
  lcd.print(I_average * U_average, 1);  //display output power with 1 decimal place
  lcd.print("W ");

  //hysteresis, so that the relay doesn't turn on/off repeatedly when crossing the threshold
  if(volts > VoltageThreshold){
    digitalWrite(RELAY, HIGH);
    VoltageThreshold = 13;
  }
  if(volts<VoltageThreshold){
    digitalWrite(RELAY, LOW);
    VoltageThreshold = 13.5;
  }
  
  analogWrite(FAN, Fanspeed);
  
  delayMicroseconds(20);
}

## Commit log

2022-02-28 renamed schematic
2022-02-28 psu arduino code
2022-02-28 schematic on which this psu was based
2022-04-26 Eagle files of pcbs
    [rectifier_board.brd, rectifier_schematic.sch, regulator_board.brd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]
2022-04-26 pdf for homemade pcbs (already mirrored)
2023-02-20 renamed folders
    [rectifier_board.brd, rectifier_schematic.sch, regulator_board.brd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]
